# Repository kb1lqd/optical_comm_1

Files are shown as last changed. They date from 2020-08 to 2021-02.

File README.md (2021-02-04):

# optical_comm_1
Adventures in optical communications

# Lessons Learned

## Post PCB Order

Getting back into KiCAD after many years away and while focusing on my primary job and life has brought many challenges to this project. Here's the list of items I noted in the design and layout.

* I need a solid workflow for KiCAD for Symbols, Footprints, and library organization
  * I need a plan for how I want my own "Library" and process for making new boards/parts to lower the mental thought needed
  * Symbol checklist
  * Footprint Checklist
  * Sch/PCB Checklist
  * Create a template for OshPark 2/4 layer (and other vendors) to simplify future projects
* The scope of  this project ended up being quite large
* I had very little time outside of work/life to do this that intersected with my want to work on it
  * Break projects into small chunks
  * The multiplexing of jumping into this for an hour and out was very inefficient.
  * Lower the barrier to just getting a PCB in hand, refining my process, etc...
* I need more practice with KiCAD - it's different enough from Altium to be annoying and I'm not up for sitting through issues or planning after a day/week of work.

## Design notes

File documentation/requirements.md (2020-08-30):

# Requirements

### Transmitter

| Req # | Requirement | Rational |
|---|---|---|
| 1 | The transmitter shall implement amplitude modulation at baseband. | Derived |
| 2 | The transmitter shall exhibit at least 4khz of bandwidth | To support voice operations |
| 3 | The transmitter shall accept an input signal from an audio headphone output interface | Use of a computer headphone jack to provide source signals into the transmitter|
| 4 | The transmitter shall accept an input signal from a microphone interface | Use of an external microphone to provide source signals into the transmitter|
| 5 | The transmitter shall be powered from a 5V +/-250mV source | USB power |

### Receiver

| Req # | Requirement | Rational |
|---|---|---|
| 1 | The receiver shall implement amplitude modulation at baseband. | Derived |
| 2 | The receiver shall exhibit at least 4khz of bandwidth | To support voice operations |
| 3 | The receiver shall output demodulated signals from an audio headphone output level interface | Monitor headphone output|
| 4 | The receiver shall output demodulated signals from a microphone output level interface | Output provided for computer microphone input interface|
| 5 | The receiver shall be powered from a 5V +/-250mV source | USB power |

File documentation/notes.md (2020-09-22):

# Notes

## Design Notes

#### Headphones Input

Online research suggests the maximum voltage output of a headphone jack varies wildly. The output circuit itself is a low impedance amplifier that is primarily a current amplifier. It is reasonable to think that the high impedance input of the input circuits / op-amps will easily allow a maximum voltage on the input.

#### Bofeng Electret Microphone

I would like to use some spare Bofeng earpieces I have laying around. I couldn't find info sufficient to use so I cracked on open and measured while located plugged into my radio.

##### Input
* Measured ~3mVp-p while whistling at ~1.8KHz
* Electret mic is powered by 3.3V

##### Output
* ~Comfortable volume produced ~1Vp-p input earpieces
* Max volume produced ~8Vp-p

## Notes

### 9/7/2020

Today I was able to place a bulk of the transmitter circuit in LTSpice in generic format. I settled on a basic current source with pass transistor topology driving up to ~20mA at 5V. The 2 inputs are "headphones" and a "mic" input, I measured my Bofeng radio headset to get an idea where this will be in terms of signal levels and requirements.

I have been more or less rough estimating operating points, I need to go back and do the math out for fine tuning and stability. This circuit could be made to drive much higher loads if the pass transistor is made adequate, although this is a "linear" output that will dump a lot of heat into the transistor!

### 9/8/2020

Today I dove into the microphone amplifier circuitry. Assuming a nominal microphone input of 1-5mV from the electret microphone I calculated the following gains required to achieve a nominal maximum control voltage of 2.4Vp-p.

* Maximum Gain (5mVp-p): 1200 V/V   
* Minimum Gain (1mvp-p): 240 V/V

To realize this it is best split into two amplifier sub-circuits as to provide a solid fixed gain pre-amp and a variable gain final amplifier. Driving a 1200 V/V gain at 4KHz would require ~10MHz gain bandwidth product op-amp as well, easy to obtain but splitting the gain further eases this requirement. The AD8648 provides over 20MHz bandwidth and is relatively cheap.

ADS8648 Key Specs

* Vos = 2.5mV Maximum
  * All gain stages are AC coupled, 2.5mV at full scale 2.4V is negligable
* Is = 50pA Maximum worst case
  * With a 10K gain resistor this is only 0.5mV
  * With gain should match this on each input.
* Voh = 4.9V at 1mA over temp
  * Not an issue
* Vol
  * 40mV maximum over temp at 1mA.
  * Not an issue.
* GBP = 24 MHz
* Phase Margin = 74 degrees

I created a pre-amp of gain 100 V/V, the secondary gain stage is required to provide a variable 2.4V/V to 12 V/V. This is achieved by using a potentiometer in series with a minimum feedback resistor.

### 9/13/2020
Starting tonight off I need to work on the following:
* Calculate op amp gains (DONE)
  * Completed, GBP also calculated and are good.
* Calculate filter values into the LED driver at 4KHz -3dB (DONE)
* Choose MOSFET (DONE)
  * PMBF170,215	from NXP looks good. I imported the model into LTSpice. Looks good, maybe a bit lower output at lower freq.
* TO-DO: Double check op-amp stability
* Start KICAD

### 9/17/2020

TO-DO:
* Calculate:
  * Op-amp stability
  * Op-amp capacitive driver (AC coupling capacitance)
* Start KiCAD (DONE)

Status:
I was able to start KiCAD and get a new library added for the AD8648 IC. I did high level sheet creation for the transmitter and the first pass drop in of components for the microphone pre-amp stage.

### 9/20/2020

* I used LTSpice to do a quick check on op-amp stability.
* I changed the single-supply op-amp design to a voltage divider between 5V input.

### 9/21/2020

* I created an open items list on google drive
* I added audio jack with pin-outs for a kenwood style mic connector

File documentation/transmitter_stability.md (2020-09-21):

# Stability Analysis
I used open-loop analysis in LTSpice to quickly check for gain/phase margin in the op-amp circuits for the transmitter.

## Microphone Pre-amp
The microphone pre-amp is expected to have a gain of 100 V/V on the first stage and a maximum gaing of 12 V/V on stage 2. This leaves the expected bandwidth of the op-amps given the gain-bandwidth product at:

* Stage 1: 240 KHz
* Stage 2: 2.0 MHz

I setup LTSpice to perform open loop gain/phase analysis as shown below.

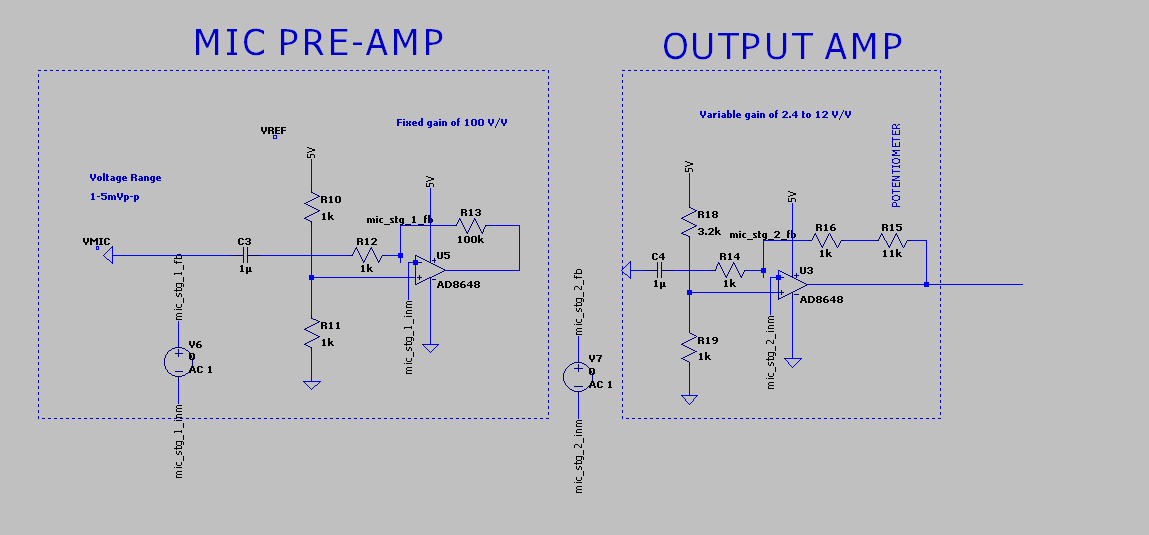
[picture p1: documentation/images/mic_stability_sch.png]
Microphone Pre-Amp Stability Analysis Schematic


The two stages showed good phase and gain margin as shown below.

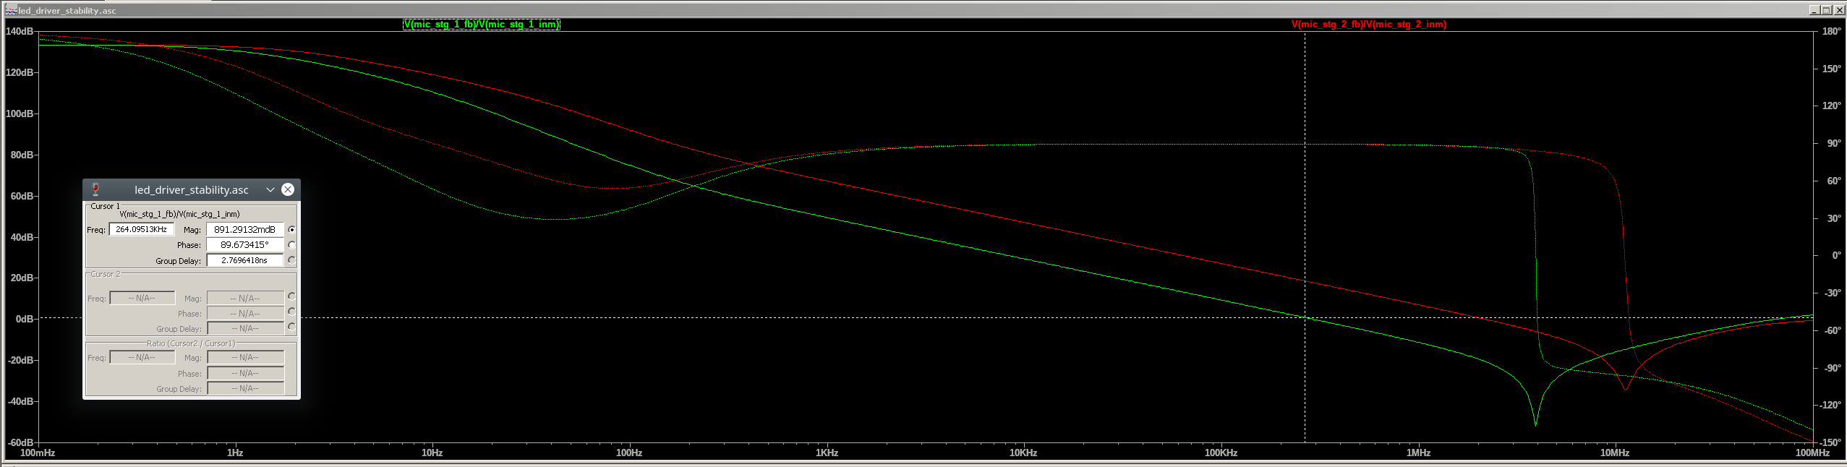
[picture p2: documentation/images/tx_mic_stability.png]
Pre-amp stage 1 gain/phase margin


Stage 1 showed ~90 degree phase margin with a unity gain bandwidth of 264 KHz, right where it was expected. Although not marked gain margin is very high, >>20dB.

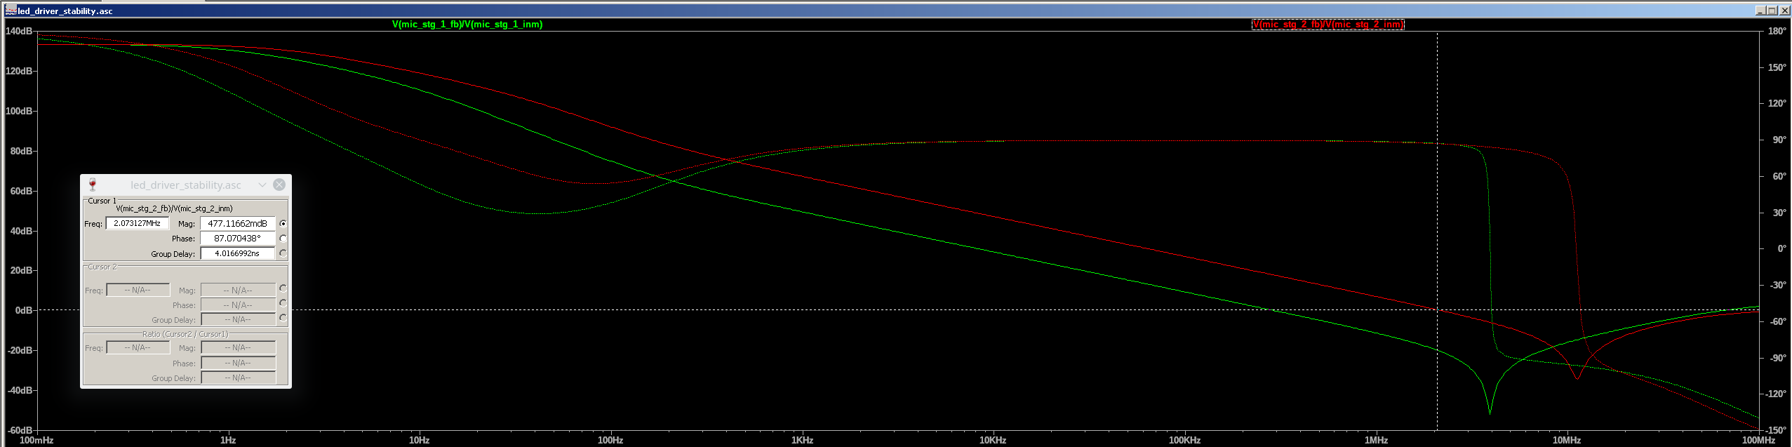
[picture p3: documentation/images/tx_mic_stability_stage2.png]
Pre-amp stage 2 gain/phase margin


Stage 2 showed ~87 degree phase margin with a unity gain bandwidth of ~2 MHz, right where it was expected. Although not marked gain margin is very high, >>20dB.

This is expected to be stable.

## Headphone Input Pre-amp
The headphone amplifier is expected to have a unity gain of 1 V/V as the input is just attenuating the strong expected headphone driver signal. This leaves the expected bandwidth of the op-amps given the gain-bandwidth product at:

* Expected Bandwidth: 24 MHz

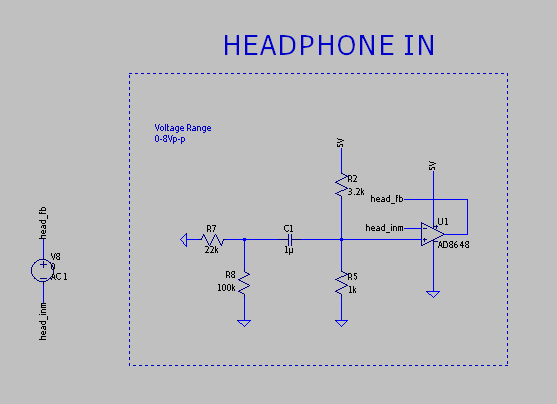
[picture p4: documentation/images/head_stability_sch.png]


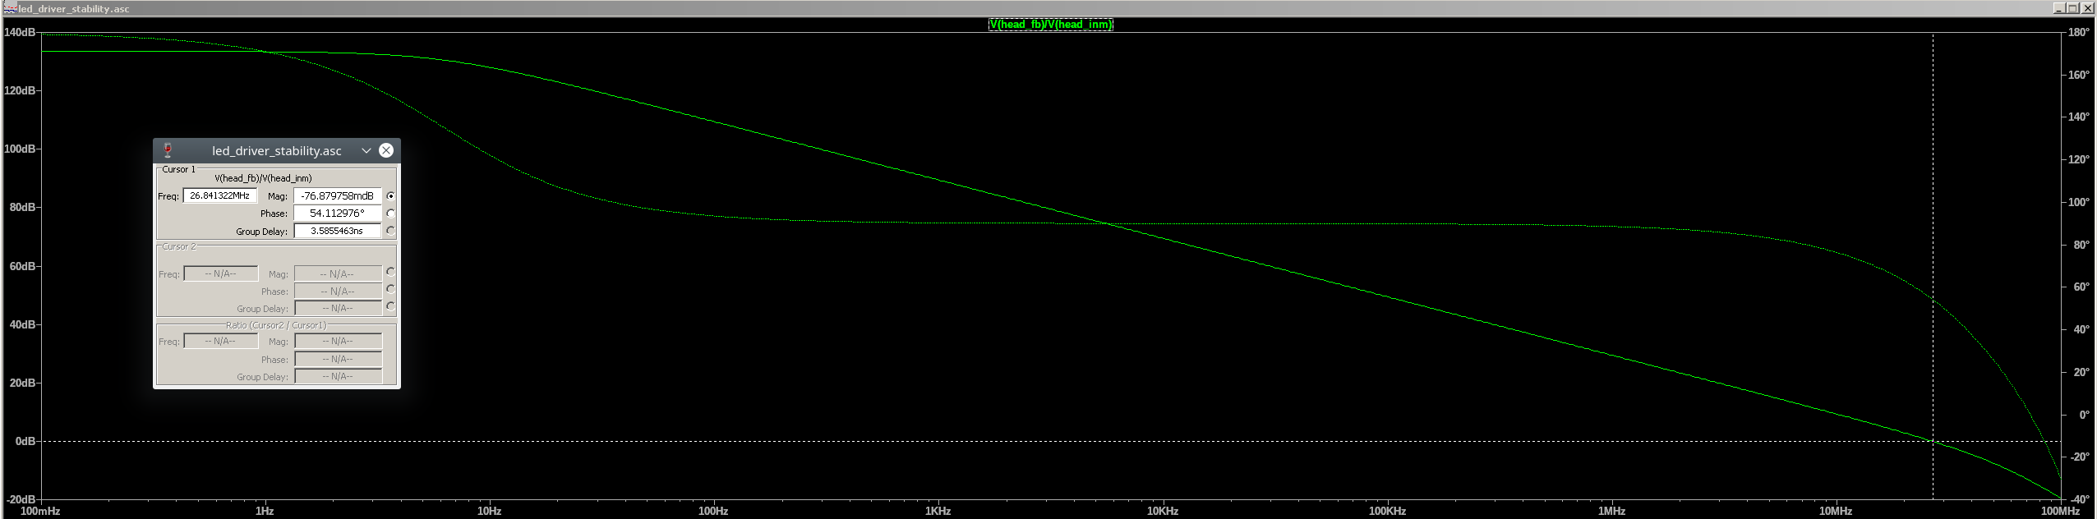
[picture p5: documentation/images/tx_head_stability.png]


The bandwidth is ~26 MHz which is approximately what was expected and a phase margin of ~56 degrees. The gain margin is not shown but is 13.7dB.

This is expected to be stable.

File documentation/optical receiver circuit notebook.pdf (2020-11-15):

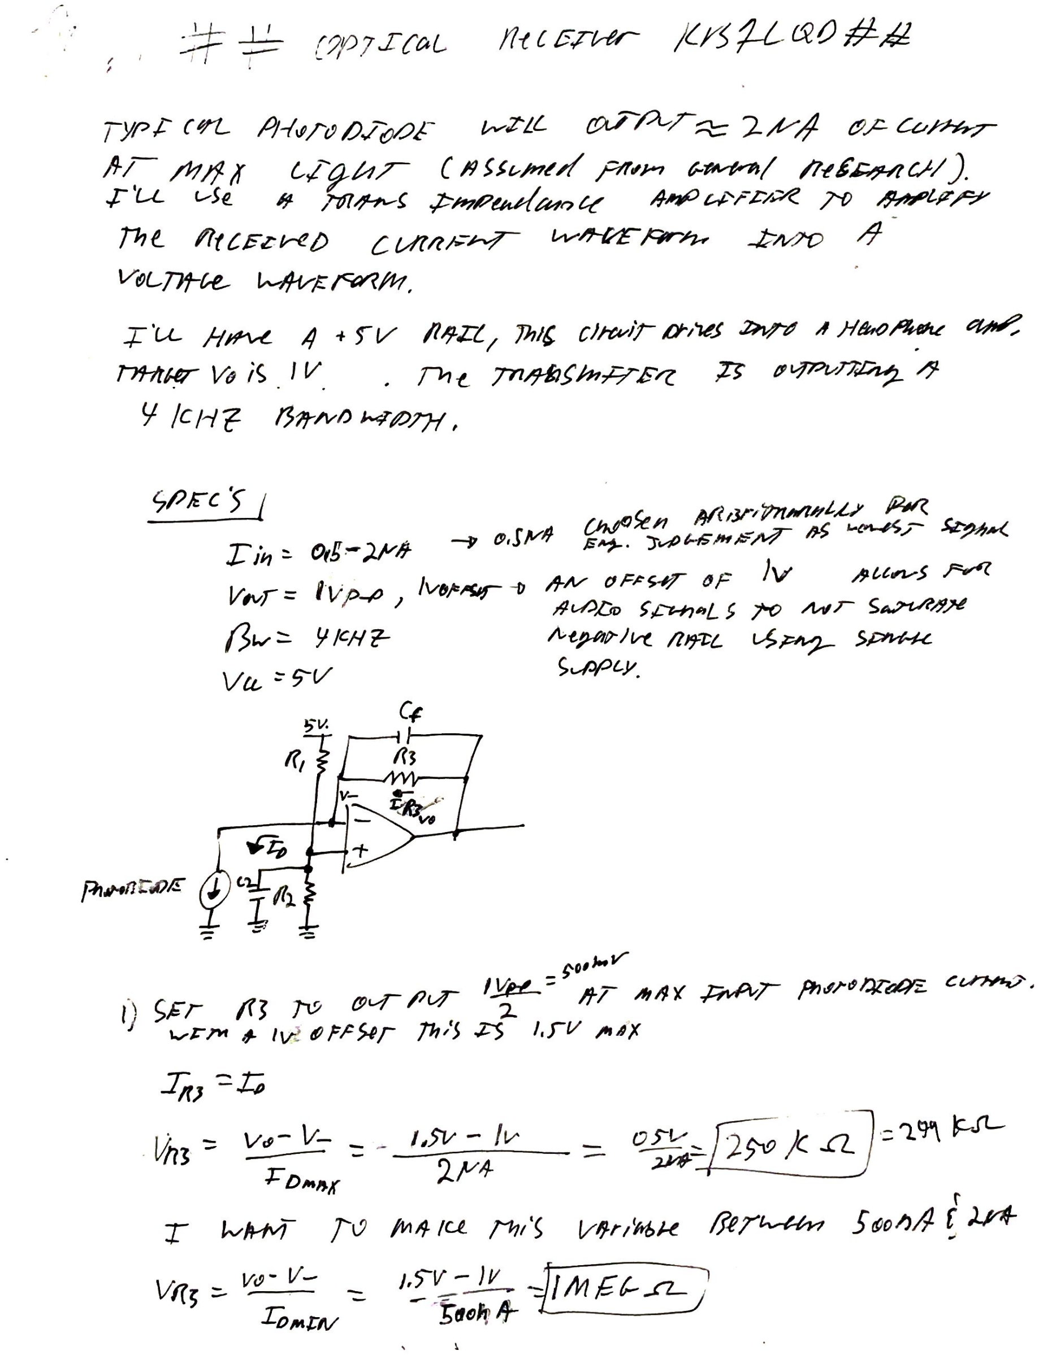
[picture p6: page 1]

(

# 1 (OPTICAL

neceiver Krstl.QD##
Typ Ece PHOTO DIODE WILL
aTnt 22NA of contat
I'LL use A Trans Impenelance And IR 70 Amplify The RECEIVED
CURRENT WAVE Form Inro
VOLTALE WAVEFORM,
I'll Have A +5V RAIL, This cirait prises Into A Meno Phone ano, Tranvet vois TV
The TRASSMETER IS OUTPUTTING A
4 IHZ BANDWIDTH,
SPEC'S
I in = 0.5-2N
→ OSMH choosen Arnimmmly PAR Eng. JUDGEMENT AS memesi Segnal lv
Allan's
Vous = lipe, vofas & AN OFFSET OF AUSEO stanals to not SavrRATE Bw=4KHZ
Negative RAIL LSing sombre Va=5v
SUPPLY
CA
50.
13
E ERSO
To
Phwonine A
16
I'
= 500mor
Ivee
out it
U) SET R3 to
AT MAX INPUT PhorontODE curr. him in offset this as usu max
In = Ie
Vorh
Uns
= 299 kr
FDMAX
200
1,5V-250kr
2NA
Want To maice this varimore Bernen 500nA & 20t -
1.5V-IV JIMEG az
IOMIN

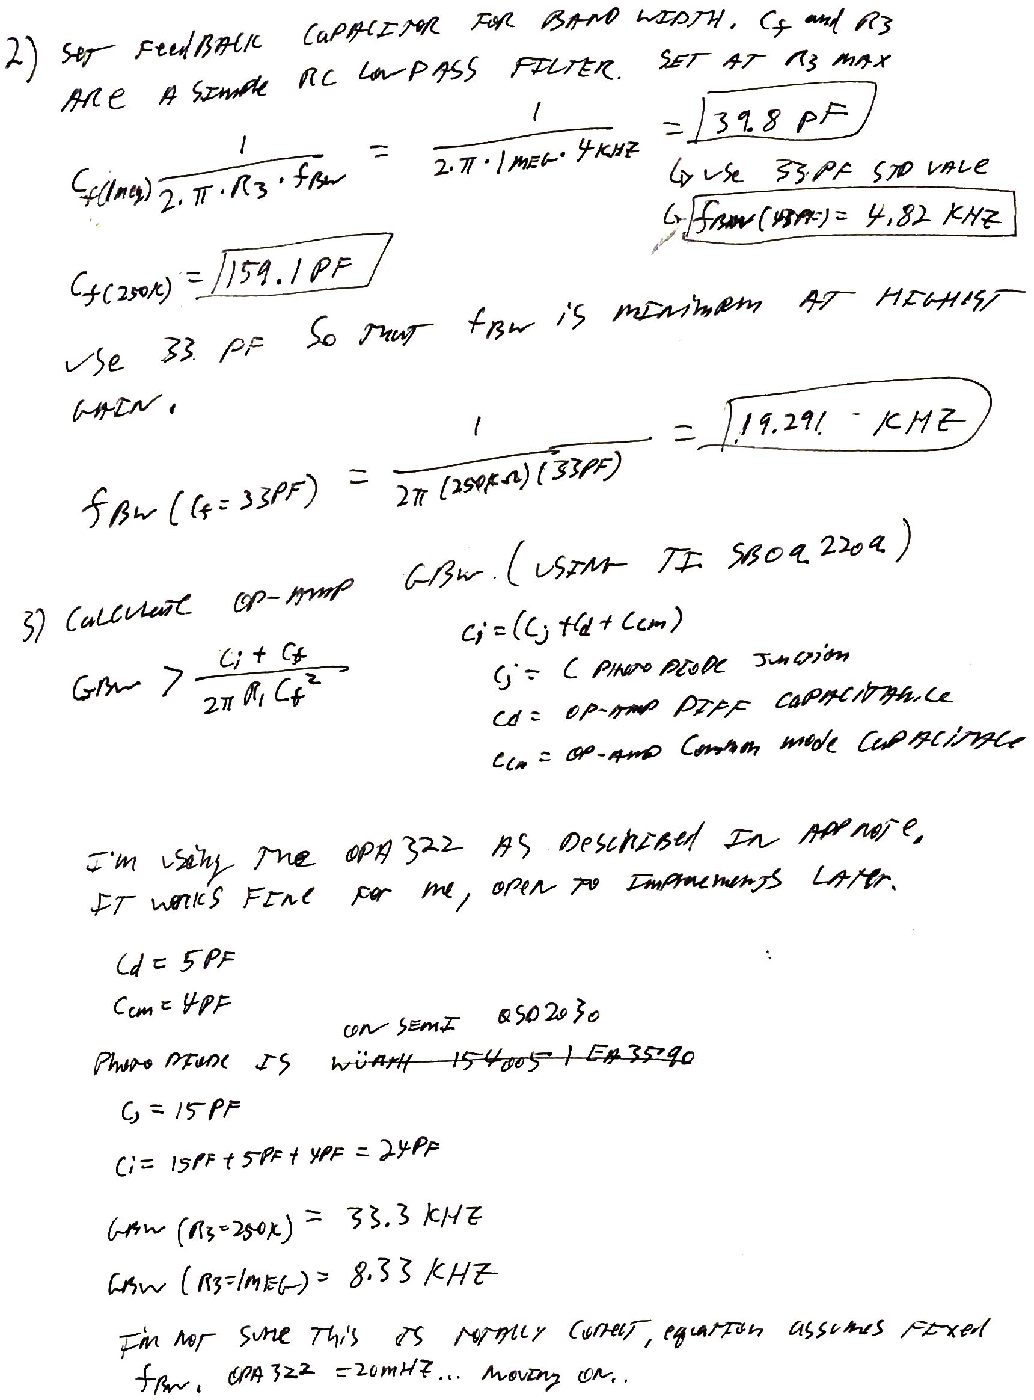
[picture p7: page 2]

SET AT 3 MAX
- for
AT HIGHEST
2) ser feel BACK CAPACITOR FOR BANO WIDTH, C, and R3 Are A simple RC Low-PASS FILTER.
= 1398 pf
Filmo) 2. I 13. f
2.7 ./ MER 4KNZ
louse 3zPF STO VALE
Glow (489x) = 4,82 KHZ
462001) = /159.1 PF
use
33. Pe
So that for is minimam
GHIN,
- 1.19.294
119.291 KHZ
fBw (( = 33PF)
GBwr. (usina TI SB0a 220a) C;' =((; Het com)
GB 7
G=C Pharo mole Jimorion
co= OP-AMP PIFF Capacitance
can P-Am Common mode Capacionce 1
=
277 (25940) (33PF)
- mm
3) Calcurant
C; + Ct
20 Ri Co²
I'm using the OPA 322 AS Deschised In App note, IT works Fine
for me,
open to Impruements LAT.
(d = 5PF
Com=YPE
on SEMI
Q50 20 30
WHATH 154005 LEA3590
Pharo mune IS
C = 15PF
(i= ISPF 15 PF + YPF = 24PF
Grow (R3=250x) = 33.3 kHz
how (R3=1MEG) = 8.33KHZ
I'm not sure This 75 mly Cuneet, equarton assumes exer for. ERA 322 =20mH?...
moving on.

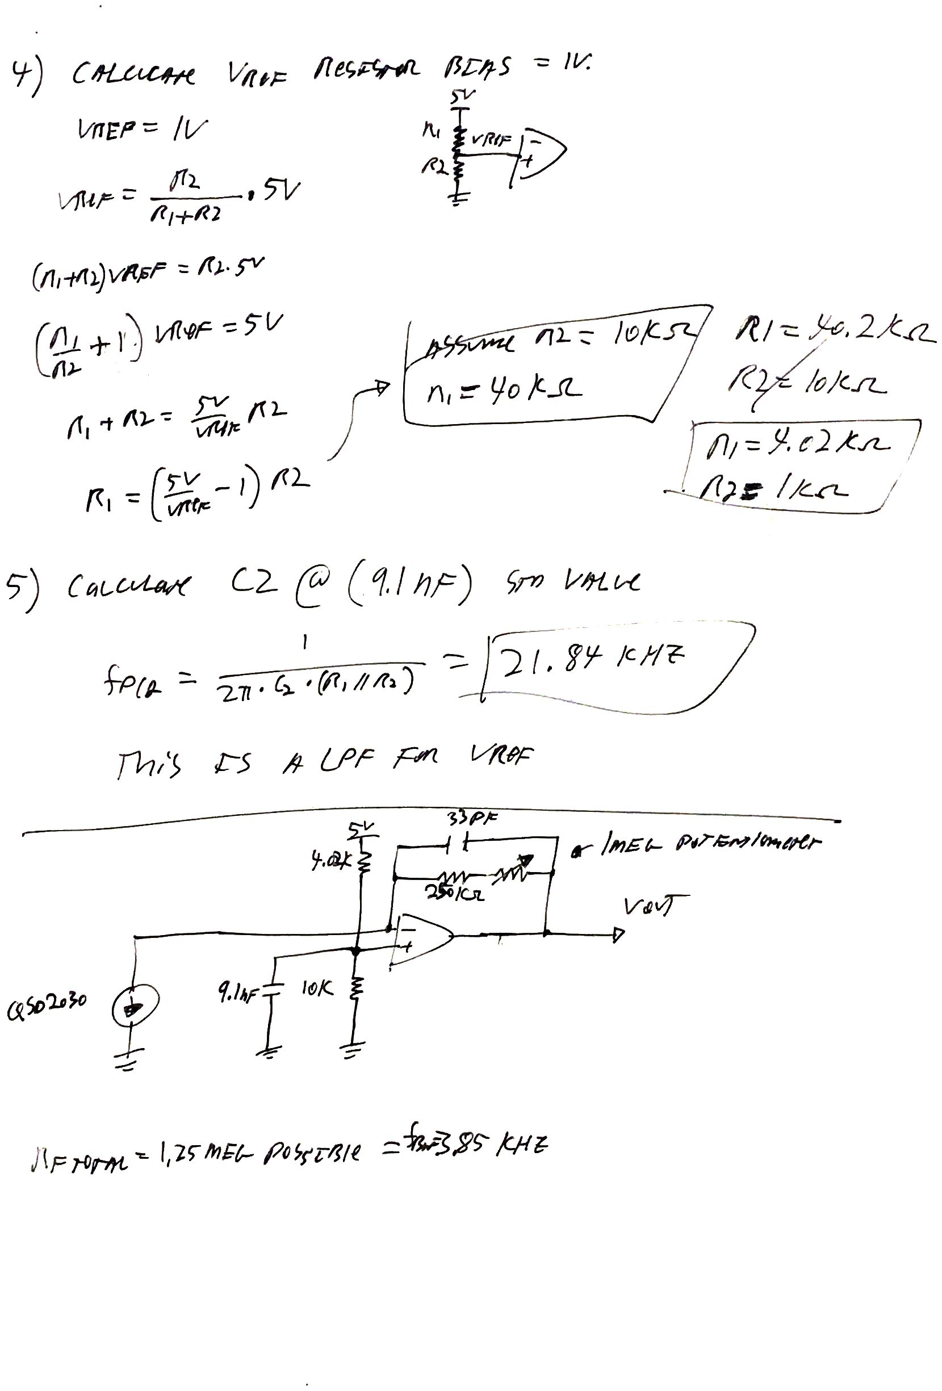
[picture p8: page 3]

= IV.
4) Calculate VroE nesesper BIMS sv
VREP = IV
no VRF
R2
..5V
era
R1+R2
(1, +92) VIREF
= 12.50
+1) nof=54
î
mir
S
1, +R2= R2
R. E
Lassume a2= loks Ri= 10.2ks n = 40kh Rhe loves
ni=1.02 kr
Elka
(su E-1) 22
5) Calculare CZ @ (.9.1 HF) SM Value face = 27627,16) = 21.84 *47
This IS ALPF FR VROF
33PF
IMEG PUTEM omever
4.at Z
moto
250142
vort
9.10F
TOK
Q502630
- from 385 kHz
From = 1,25 MEG possible =

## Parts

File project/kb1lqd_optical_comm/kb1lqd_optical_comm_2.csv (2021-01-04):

Id | Designator | Package | Quantity | Designation | Supplier and ref
1 | U2,U5 | SOIC-8_3.9x4.9mm_P1.27mm | 2 | AD8646
2 | H4,H3,H2,H1 | MountingHole_4.3mm_M4_DIN965_Pad | 4 | MountingHole_Pad
3 | J6,J3,J1 | CUI_SJ1-3523N | 3 | SJ1-3523N
4 | SW1,SW3,SW2 | SW_EG1213 | 3 | EG1213
5 | C20,C12,C6 | C_0805_2012Metric | 3 | DNP
6 | U4 | TPA6111A2D | 1 | TPA6111A2D
7 | U3 | SOIC-8_3.9x4.9mm_P1.27mm | 1 | ADA4610-1
8 | RV2,RV1 | Molex_KK-254_AE-6410-04A_1x04_P2.54mm_Vertical | 2 | 50k
9 | R34 | R_0805_2012Metric | 1 | 100k
10 | R33,R32,R17,R4,R3,R1 | R_0603_1608Metric | 6 | 0
11 | R31,R30,R29,R28,R26,R25,R13,R8,R7,R6,R5,R2 | R_0603_1608Metric | 12 | 10k
12 | R27 | R_0603_1608Metric | 1 | 500k
13 | R24,R23,R22,R20,R19,R15,R10 | R_0603_1608Metric | 7 | 1k
14 | R21,R18 | R_0603_1608Metric | 2 | 3.24k
15 | R16,R14,R11,R9 | R_0603_1608Metric | 4 | 3.2k
16 | R12 | R_0603_1608Metric | 1 | 140
17 | Q1 | SOT-23 | 1 | PMBF170
18 | J5 | Molex_KK-254_AE-6410-02A_1x02_P2.54mm_Vertical | 1 | Conn_01x02_Male
19 | J4 | Molex_KK-254_AE-6410-04A_1x04_P2.54mm_Vertical | 1 | Conn_01x04_Male
20 | J2 | CUI_SJ-2509N | 1 | SJ-2509N
21 | D2 | TO-18-2 | 1 | ODD-1W
22 | D1 | LED_D5.0mm | 1 | VLCS5830
23 | C23,C17,C9 | C_0805_2012Metric | 3 | 100nF
24 | C22,C21 | C_0603_1608Metric | 2 | DNP
25 | C19,C18,C15,C14,C13,C11 | C_1206_3216Metric | 6 | 1uF
26 | C16 | CP_Elec_5x5.3 | 1 | 10uF
27 | C10 | C_0603_1608Metric | 1 | 33pF
28 | C8 | C_0805_2012Metric | 1 | 6.8nF
29 | C7,C5,C4,C3,C2 | C_1206_3216Metric | 5 | 1u
30 | C1 | C_0805_2012Metric | 1 | 3.9n

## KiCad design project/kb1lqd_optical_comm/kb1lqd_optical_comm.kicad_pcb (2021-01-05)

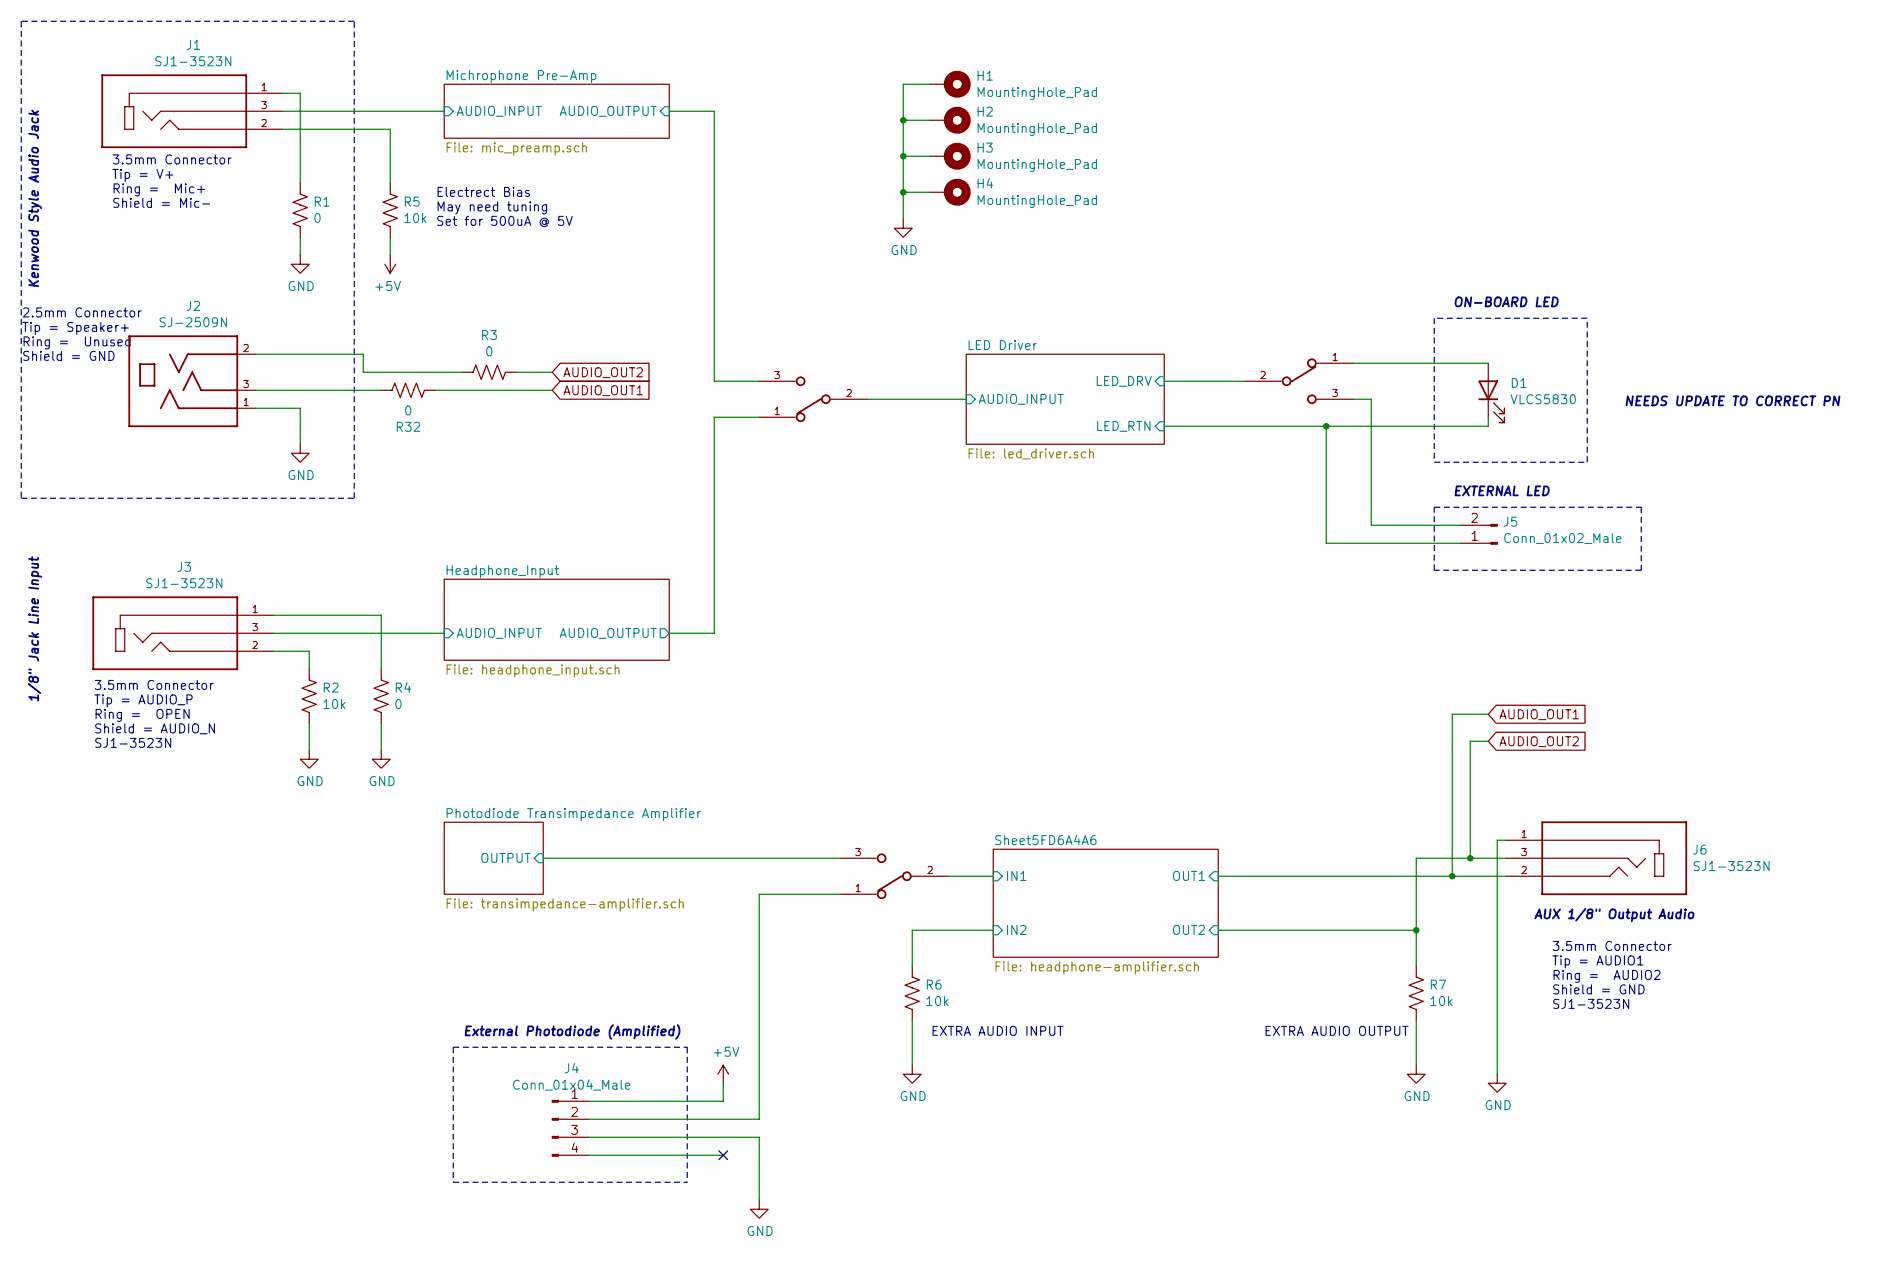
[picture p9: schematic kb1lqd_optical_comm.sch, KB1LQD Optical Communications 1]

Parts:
D1: VLCS5830; LED_D5.0mm
H1, H2, H3, H4: MountingHole_Pad; MountingHole_4.3mm_M4_DIN965_Pad
J1, J3, J6: SJ1-3523N; CUI_SJ1-3523N; PARTREV 1.02
J2: SJ-2509N; CUI_SJ-2509N; PART_REV B
J4: Conn_01x04_Male; Molex_KK-254_AE-6410-04A_1x04_P2.54mm_Vertical
J5: Conn_01x02_Male; Molex_KK-254_AE-6410-02A_1x02_P2.54mm_Vertical
R1, R3, R4, R32: 0; R_0603_1608Metric
R2, R5, R6, R7: 10k; R_0603_1608Metric
SW1, SW2, SW3: EG1213; SW_EG1213

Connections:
+5V: J4.1, R5.2, SW3.2; also elsewhere on the board
/Headphone_Input/AUDIO_INPUT: J3.3; also elsewhere on the board
/Headphone_Input/AUDIO_OUTPUT: SW1.1; also elsewhere on the board
/LED Driver/AUDIO_INPUT: SW1.2; also elsewhere on the board
/LED Driver/LED_RTN: D1.1 (K), J5.1; also elsewhere on the board
/Michrophone Pre-Amp/AUDIO_INPUT: J1.3; also elsewhere on the board
/Michrophone Pre-Amp/AUDIO_OUTPUT: SW1.3; also elsewhere on the board
/Photodiode Transimpedance Amplifier/OUTPUT: SW2.3; also elsewhere on the board
/Sheet5FD6A4A6/IN1: SW2.2; also elsewhere on the board
/Sheet5FD6A4A6/IN2: R6.1; also elsewhere on the board
AUDIO_OUT1: J6.2, R32.2; also elsewhere on the board
AUDIO_OUT2: J6.3, R3.1, R7.1; also elsewhere on the board
GND: H1.1, H2.1, H3.1, H4.1, J2.1, J4.3, J6.1, R1.2, R2.2, R4.2, R6.2, R7.2; also elsewhere on the board
unnamed: D1.2 (A), SW3.1
unnamed: J1.1, R1.1
unnamed: J1.2, R5.1
unnamed: J2.2, R3.2
unnamed: J2.3, R32.1
unnamed: J3.1, R4.1
unnamed: J3.2, R2.1
unnamed: J4.2, SW2.1
unnamed: J5.2, SW3.3

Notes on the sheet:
3.5mm Connector Tip = V+ Ring = Mic+ Shield = Mic-
2.5mm Connector Tip = Speaker+ Ring = Unused Shield = GND
Electrect Bias May need tuning Set for 500uA @ 5V
ON-BOARD LED
EXTERNAL LED
NEEDS UPDATE TO CORRECT PN
External Photodiode (Amplified)
3.5mm Connector Tip = AUDIO_P Ring = OPEN Shield = AUDIO_N SJ1-3523N
EXTRA AUDIO INPUT
EXTRA AUDIO OUTPUT
3.5mm Connector Tip = AUDIO1 Ring = AUDIO2 Shield = GND SJ1-3523N
AUX 1/8" Output Audio
Kenwood Style Audio Jack
1/8" Jack Line Input

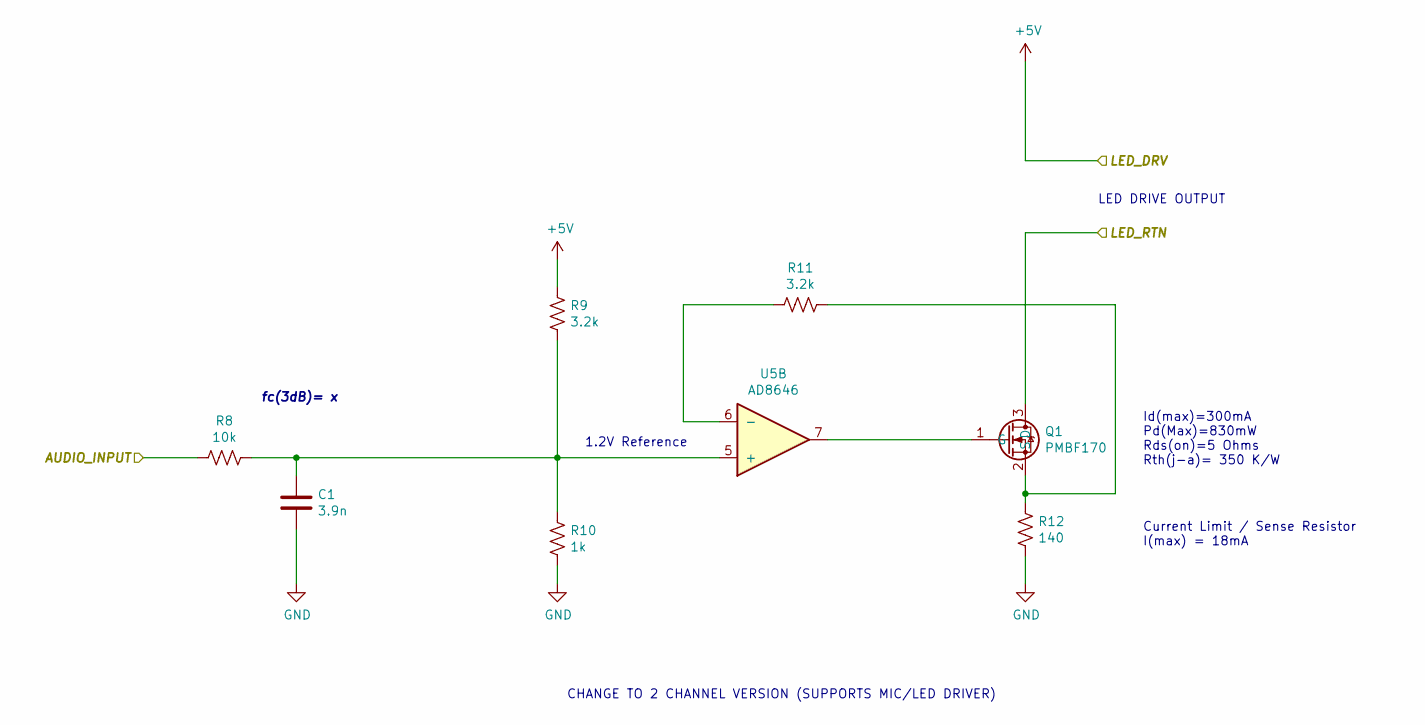
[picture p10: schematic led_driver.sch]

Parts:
C1: 3.9n; C_0805_2012Metric
Q1: PMBF170; SOT-23
R8: 10k; R_0603_1608Metric
R9, R11: 3.2k; R_0603_1608Metric
R10: 1k; R_0603_1608Metric
R12: 140; R_0603_1608Metric
U5: AD8646; SOIC-8_3.9x4.9mm_P1.27mm

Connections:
+5V: R9.1; also elsewhere on the board
/LED Driver/AUDIO_INPUT: R8.2; also elsewhere on the board
/LED Driver/LED_RTN: Q1.3 (D); also elsewhere on the board
GND: C1.2, R10.2, R12.2; also elsewhere on the board
unnamed: C1.1, R8.1, R9.2, R10.1, U5.5 (+)
unnamed: Q1.1 (G), U5.7
unnamed: Q1.2 (S), R11.1, R12.1
unnamed: R11.2, U5.6 (-)

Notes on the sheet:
LED DRIVE OUTPUT
1.2V Reference
fc(3dB)= x
Id(max)=300mA Pd(Max)=830mW Rds(on)=5 Ohms Rth(j-a)= 350 K/W
Current Limit / Sense Resistor I(max) = 18mA
CHANGE TO 2 CHANNEL VERSION (SUPPORTS MIC/LED DRIVER)

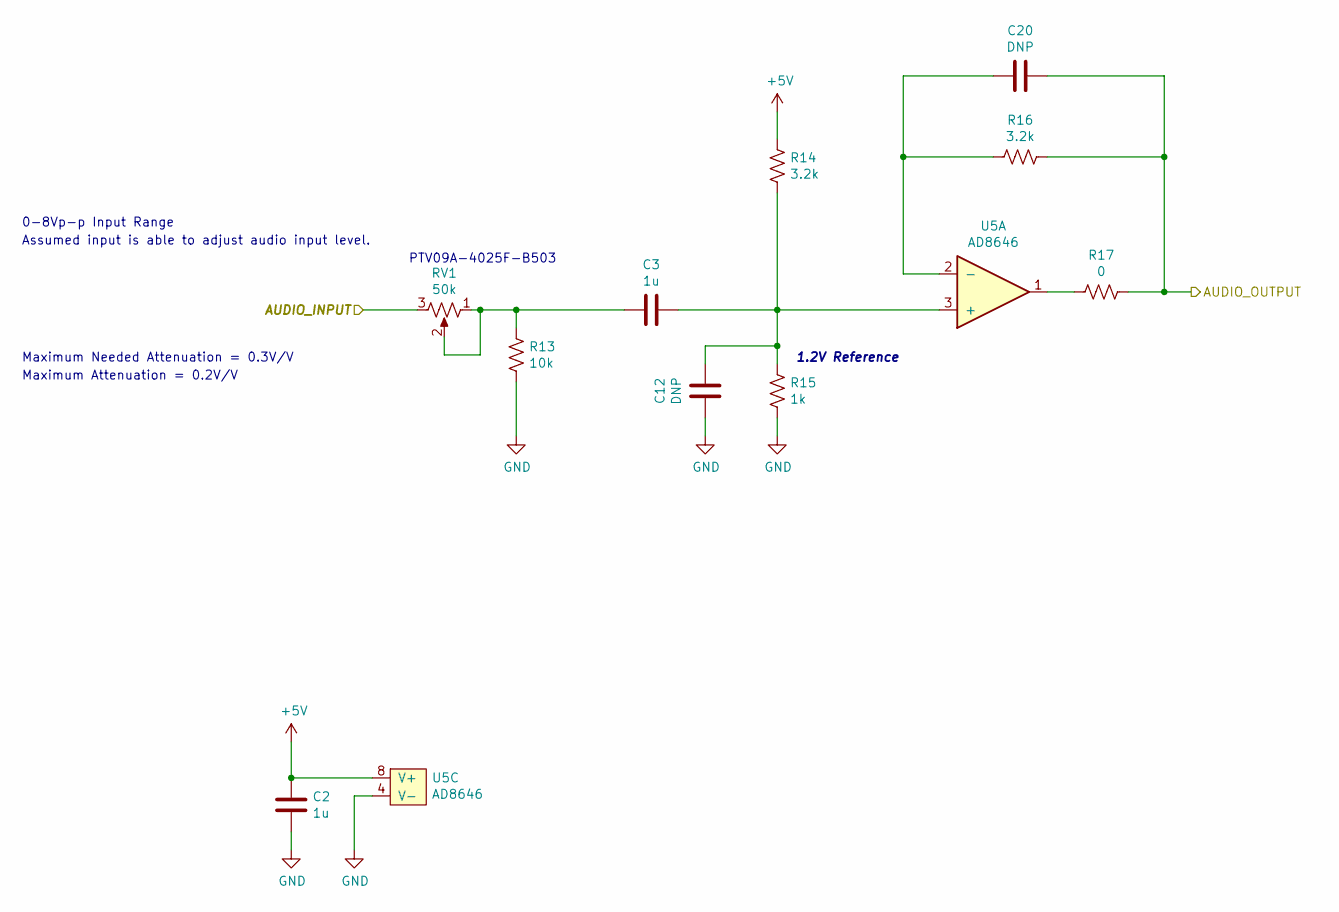
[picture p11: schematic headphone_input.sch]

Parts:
C2, C3: 1u; C_1206_3216Metric
C12, C20: DNP; C_0805_2012Metric
R13: 10k; R_0603_1608Metric
R14, R16: 3.2k; R_0603_1608Metric
R15: 1k; R_0603_1608Metric
R17: 0; R_0603_1608Metric
RV1: 50k; Molex_KK-254_AE-6410-04A_1x04_P2.54mm_Vertical
U5: AD8646; SOIC-8_3.9x4.9mm_P1.27mm

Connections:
+5V: C2.2, R14.1, U5.8 (V+); also elsewhere on the board
/Headphone_Input/AUDIO_INPUT: RV1.3; also elsewhere on the board
/Headphone_Input/AUDIO_OUTPUT: C20.1, R16.1, R17.1; also elsewhere on the board
GND: C2.1, C12.2, R13.2, R15.2, U5.4 (V-); also elsewhere on the board
unnamed: C3.2, R13.1, RV1.1, RV1.2
unnamed: C3.1, C12.1, R14.2, R15.1, U5.3 (+)
unnamed: C20.2, R16.2, U5.2 (-)
unnamed: R17.2, U5.1

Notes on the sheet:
1.2V Reference
0-8Vp-p Input Range
Assumed input is able to adjust audio input level.
Maximum Needed Attenuation = 0.3V/V
Maximum Attenuation = 0.2V/V
PTV09A-4025F-B503

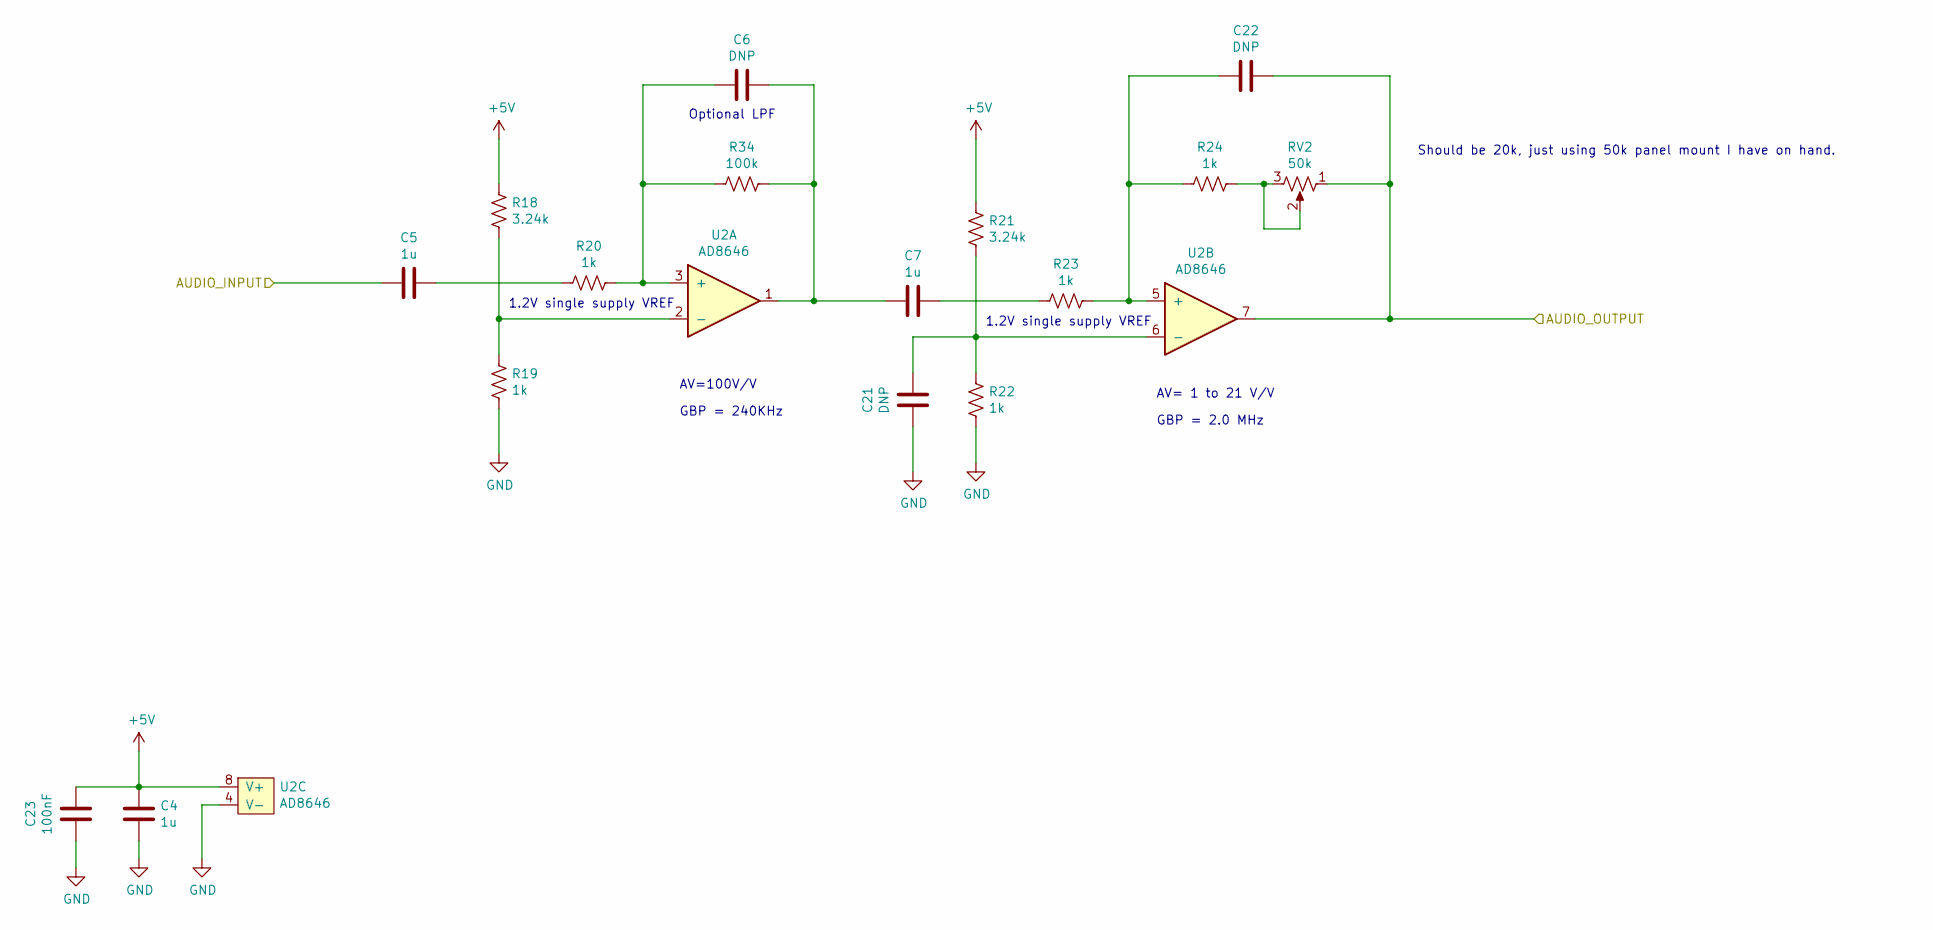
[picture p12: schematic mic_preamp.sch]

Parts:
C4, C5, C7: 1u; C_1206_3216Metric
C6: DNP; C_0805_2012Metric
C21, C22: DNP; C_0603_1608Metric
C23: 100nF; C_0805_2012Metric
R18, R21: 3.24k; R_0603_1608Metric
R19, R20, R22, R23, R24: 1k; R_0603_1608Metric
R34: 100k; R_0805_2012Metric
RV2: 50k; Molex_KK-254_AE-6410-04A_1x04_P2.54mm_Vertical
U2: AD8646; SOIC-8_3.9x4.9mm_P1.27mm

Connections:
+5V: C4.2, C23.1, R18.2, R21.2, U2.8 (V+); also elsewhere on the board
/Michrophone Pre-Amp/AUDIO_INPUT: C5.2; also elsewhere on the board
/Michrophone Pre-Amp/AUDIO_OUTPUT: C22.1, RV2.1, U2.7; also elsewhere on the board
GND: C4.1, C21.2, C23.2, R19.1, R22.1, U2.4 (V-); also elsewhere on the board
unnamed: C5.1, R20.2
unnamed: C6.1, C7.2, R34.1, U2.1
unnamed: C6.2, R20.1, R34.2, U2.3 (+)
unnamed: C7.1, R23.2
unnamed: C21.1, R21.1, R22.2, U2.6 (-)
unnamed: C22.2, R23.1, R24.2, U2.5 (+)
unnamed: R18.1, R19.2, U2.2 (-)
unnamed: R24.1, RV2.2, RV2.3

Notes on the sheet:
AV=100V/V
AV= 1 to 21 V/V
1.2V single supply VREF
GBP = 240KHz
GBP = 2.0 MHz
Optional LPF
Should be 20k, just using 50k panel mount I have on hand.

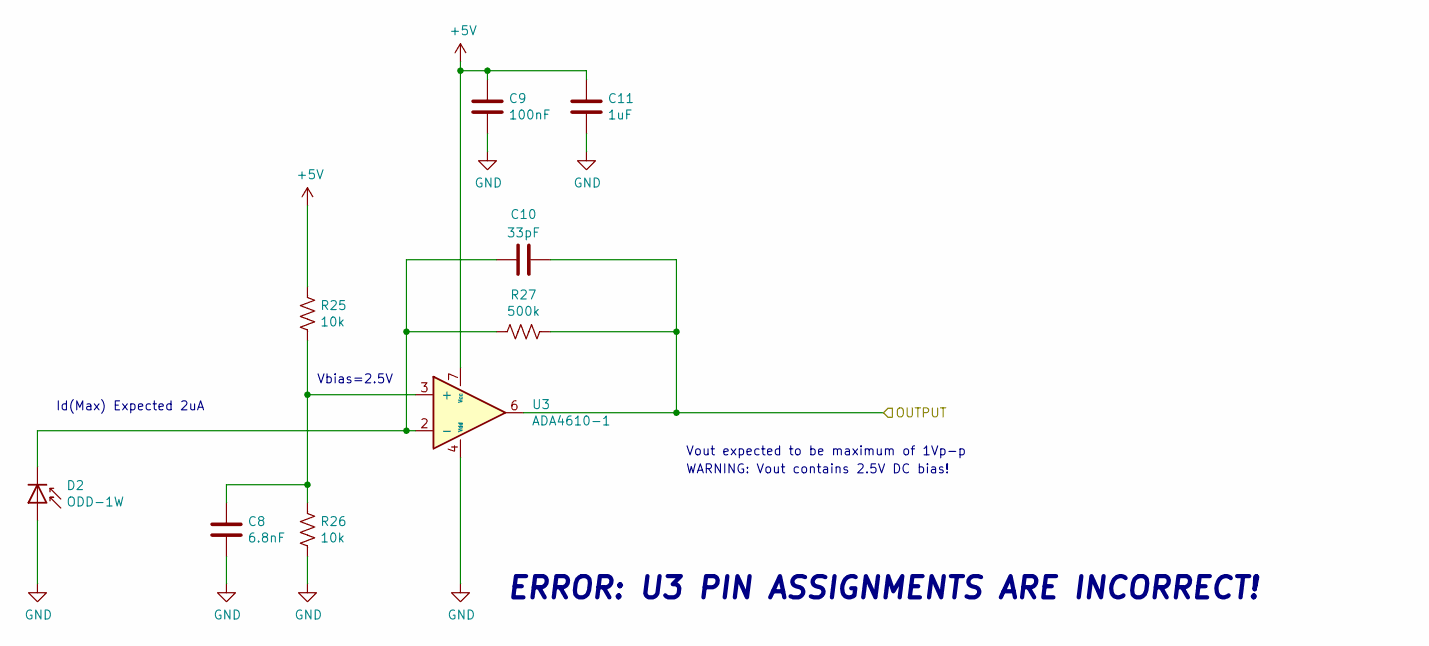
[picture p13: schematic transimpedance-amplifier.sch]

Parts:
C8: 6.8nF; C_0805_2012Metric
C9: 100nF; C_0805_2012Metric
C10: 33pF; C_0603_1608Metric
C11: 1uF; C_1206_3216Metric
D2: ODD-1W; TO-18-2
R25, R26: 10k; R_0603_1608Metric
R27: 500k; R_0603_1608Metric
U3: ADA4610-1; SOIC-8_3.9x4.9mm_P1.27mm

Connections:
+5V: C9.1, C11.1, R25.1, U3.7 (Vcc); also elsewhere on the board
/Photodiode Transimpedance Amplifier/OUTPUT: C10.1, R27.1, U3.6; also elsewhere on the board
GND: C8.2, C9.2, C11.2, D2.2 (A), R26.2, U3.4 (Vdd); also elsewhere on the board
unnamed: C8.1, R25.2, R26.1, U3.3 (+)
unnamed: C10.2, D2.1 (K), R27.2, U3.2 (-)

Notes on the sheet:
Id(Max) Expected 2uA
Vout expected to be maximum of 1Vp-p
Vbias=2.5V
WARNING: Vout contains 2.5V DC bias!
ERROR: U3 PIN ASSIGNMENTS ARE INCORRECT!

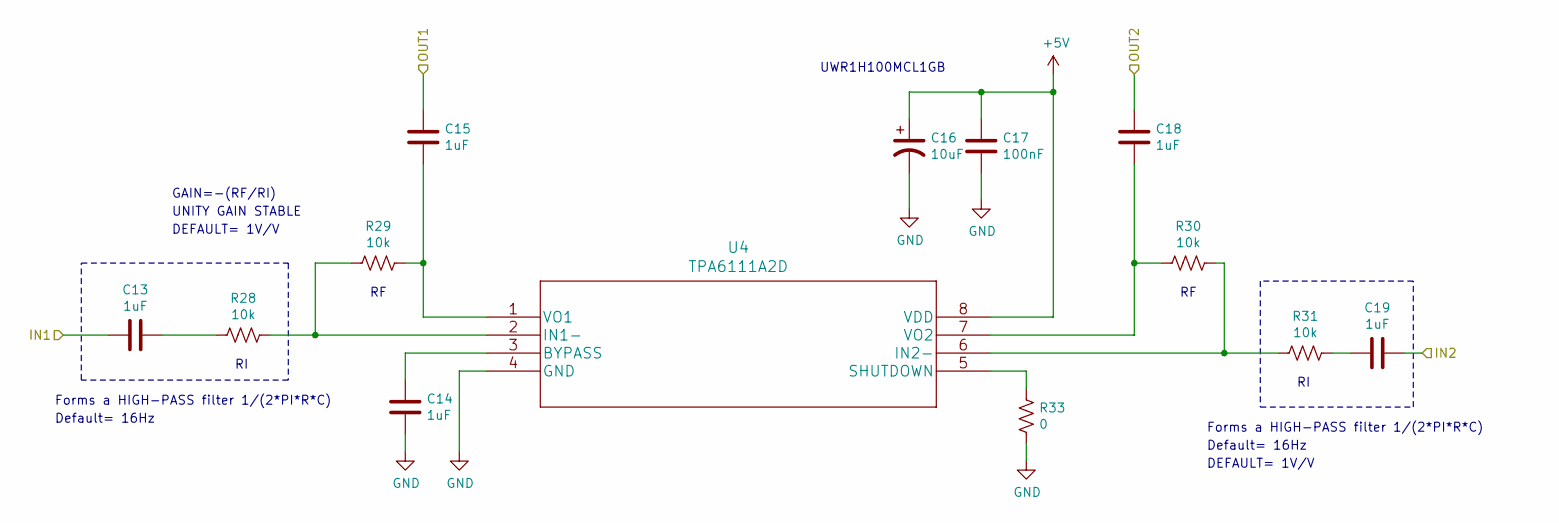
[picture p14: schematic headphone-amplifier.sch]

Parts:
C13, C14, C15, C18, C19: 1uF; C_1206_3216Metric
C16: 10uF; CP_Elec_5x5.3
C17: 100nF; C_0805_2012Metric
R28, R29, R30, R31: 10k; R_0603_1608Metric
R33: 0; R_0603_1608Metric
U4: TPA6111A2D

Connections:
+5V: C16.1, C17.2, U4.8 (VDD); also elsewhere on the board
/Sheet5FD6A4A6/IN1: C13.1; also elsewhere on the board
/Sheet5FD6A4A6/IN2: C19.2; also elsewhere on the board
AUDIO_OUT1: C15.2; also elsewhere on the board
AUDIO_OUT2: C18.2; also elsewhere on the board
GND: C14.1, C16.2, C17.1, R33.1, U4.4 (GND); also elsewhere on the board
unnamed: C13.2, R28.2
unnamed: C14.2, U4.3 (BYPASS)
unnamed: C15.1, R29.1, U4.1 (VO1)
unnamed: C18.1, R30.2, U4.7 (VO2)
unnamed: C19.1, R31.1
unnamed: R28.1, R29.2, U4.2 (IN1-)
unnamed: R30.1, R31.2, U4.6 (IN2-)
unnamed: R33.2, U4.5 (SHUTDOWN)

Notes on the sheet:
GAIN=-(RF/RI)
UNITY GAIN STABLE
Forms a HIGH-PASS filter 1/(2*PI*R*C)
Default= 16Hz
DEFAULT= 1V/V
UWR1H100MCL1GB

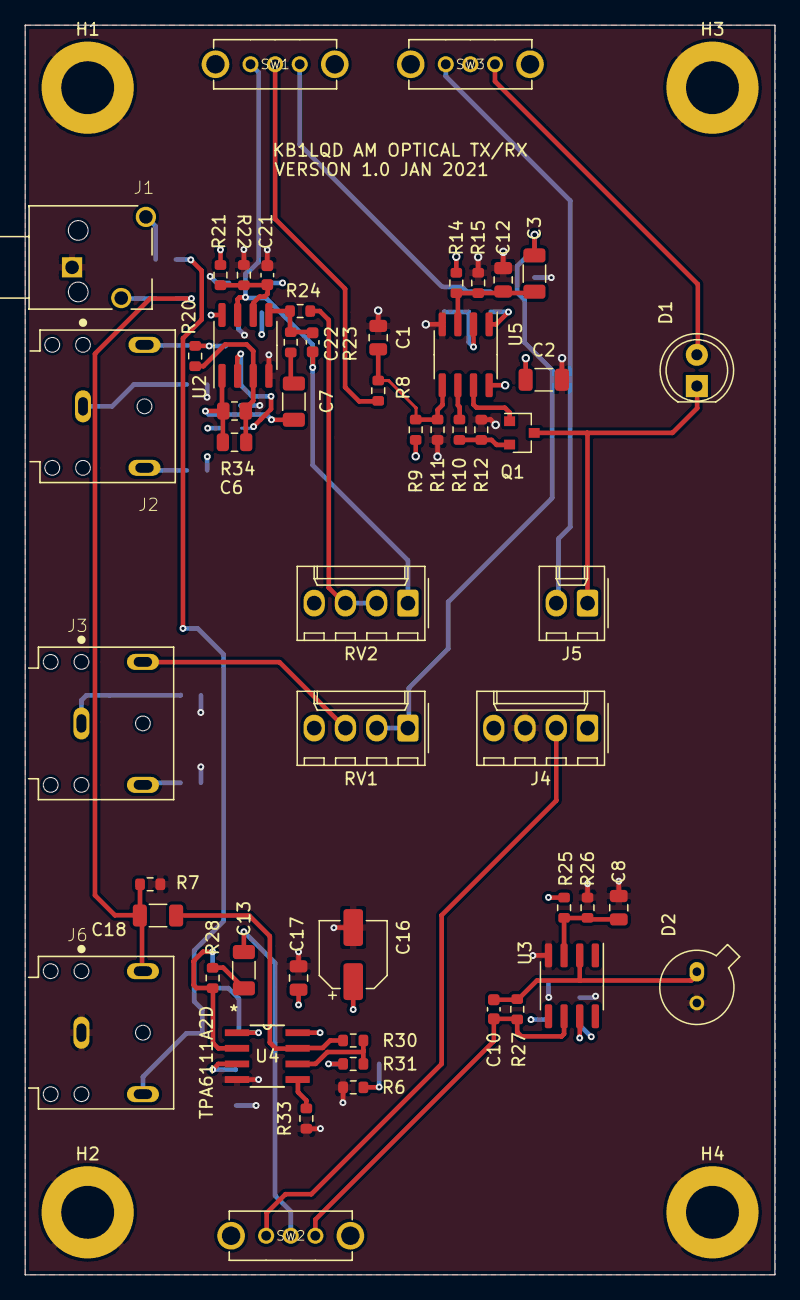
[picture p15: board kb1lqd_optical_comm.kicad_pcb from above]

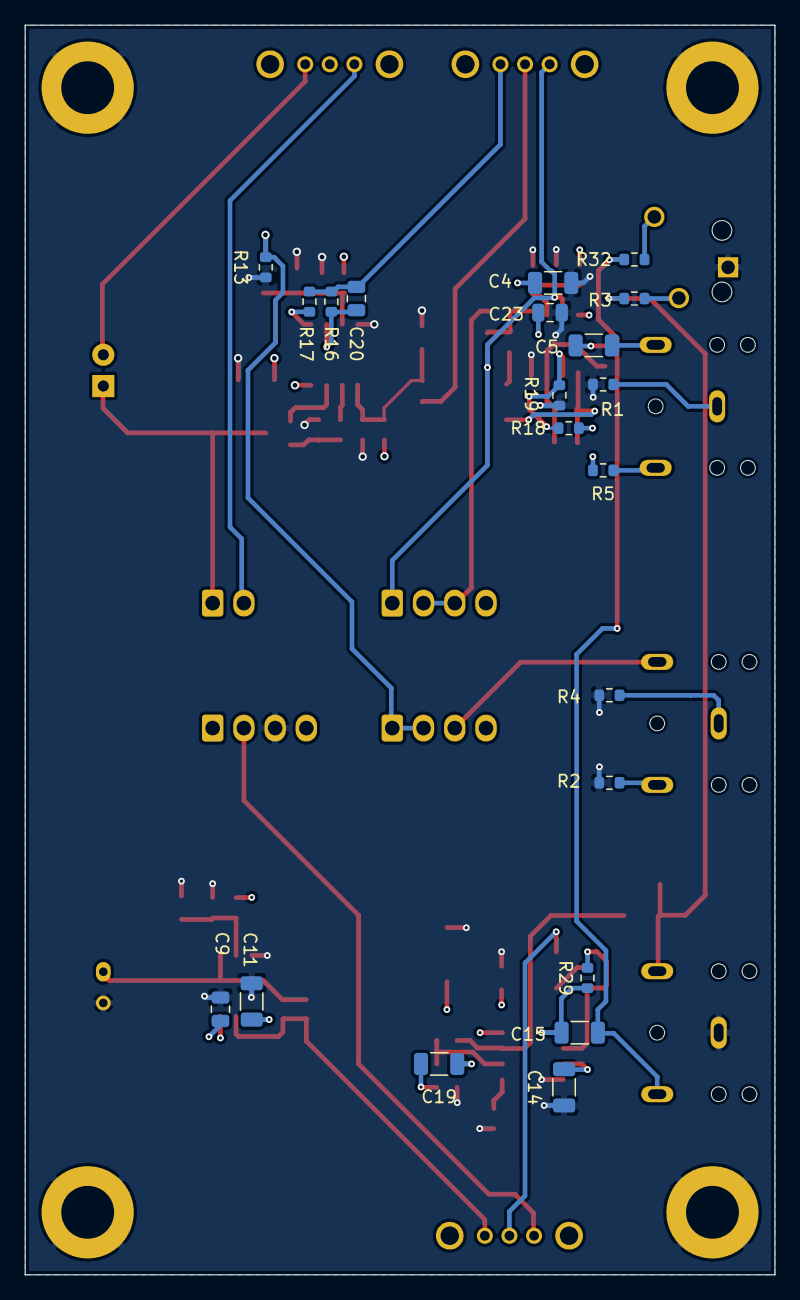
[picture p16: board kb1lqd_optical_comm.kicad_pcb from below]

Board: 4 copper layers, 61.0 x 101.6 mm, 79 parts (21 on the bottom side), 48 nets.

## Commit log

2020-09-07 Working current source
2020-09-07 Initial driver ipython.
2020-09-09 Updated mic pre-amp and output stage.
2020-09-14 Updating with RC filter, correct MOSFET.
2020-09-18 Adding KiCAD initial project.
    [headphone_input.sch, kb1lqd_optical_comm.kicad_pcb, kb1lqd_optical_comm.sch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]
2020-09-21 Updated with better values and text.
    [headphone_input.sch, kb1lqd_optical_comm.sch, led_driver.sch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]
2020-09-21 Adding updates.
    [headphone_input.sch, kb1lqd_optical_comm.sch, led_driver.sch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]
2020-09-22 Adding updates for 9/21/2020
    [headphone_input.sch, kb1lqd_optical_comm.sch, mic_preamp.sch]
2020-09-22 Updated jack todo text.
    [kb1lqd_optical_comm.sch]
2020-09-23 Adding audio jack symbols.
    [kb1lqd_optical_comm.sch]
2020-09-23 Adding KK 100 series connector.
    [kb1lqd_optical_comm.sch]
2020-09-23 Adding SPDT switch.
    [kb1lqd_optical_comm.sch]
2020-12-13 adding recevier transimpedance amp. Adding simulations.
    [headphone_input.sch, kb1lqd_optical_comm.sch, led_driver.sch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]
2020-12-13 Schematic essentially done.
    [headphone-amplifier.sch, headphone_input.sch, kb1lqd_optical_comm.sch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]
2020-12-13 Fixing ERC errors.
    [headphone-amplifier.sch, headphone_input.sch, kb1lqd_optical_comm.sch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]
2020-12-27 Updated with all footprints
    [headphone-amplifier.sch, headphone_input.sch, kb1lqd_optical_comm.sch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]
2020-12-27 Updated with osh park board template rules.
    [kb1lqd_oshpark-4layer-template.kicad_pcb]
2020-12-27 Initial placement mostly done. Outlined PCB.
    [headphone_input.sch, kb1lqd_optical_comm.kicad_pcb, led_driver.sch]
2020-12-27 Initial placement condensed.
    [headphone_input.sch, kb1lqd_optical_comm.kicad_pcb, kb1lqd_optical_comm.sch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]
2020-12-27 More placement. Ready for board outline update.
    [kb1lqd_optical_comm.kicad_pcb, kb1lqd_optical_comm.sch]
2020-12-28 Placement done.
    [kb1lqd_optical_comm.kicad_pcb]
2020-12-28 Moved silkscreen references.
    [kb1lqd_optical_comm.kicad_pcb]
2020-12-28 Most of initial routing completed.
    [kb1lqd_optical_comm.kicad_pcb]
2021-01-01 Finished initial board. Downloaded audio jack footprint is causing errors on edge cut layer.
    [kb1lqd_optical_comm.kicad_pcb]
2021-01-01 No DRC errors.
    [kb1lqd_optical_comm.kicad_pcb]
2021-01-01 Updated mounting holes. Created BOM.
    [kb1lqd_optical_comm.csv, kb1lqd_optical_comm.kicad_pcb, kb1lqd_optical_comm.sch]
2021-01-04 Updated u2 to soic 8
    [kb1lqd_optical_comm.kicad_pcb, mic_preamp.sch]
2021-01-04 Updated to new soic footprint.
    [kb1lqd_optical_comm.kicad_pcb, kb1lqd_optical_comm_2.csv]
2021-01-05 Fixed a few errors in silkscreen, found an open item error in U3 generated footprint.
    [kb1lqd_optical_comm-B_Cu.gbl, kb1lqd_optical_comm-B_Mask.gbs, kb1lqd_optical_comm-B_SilkS.gbo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]
2021-02-04 Ordered this, checked U3 and other IC's and didn't find any issues...
    [kb1lqd_optical_comm-B_Cu.gbl, kb1lqd_optical_comm-B_Mask.gbs, kb1lqd_optical_comm-B_SilkS.gbo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]
2021-02-04 Adding lessons learned post PCB order.

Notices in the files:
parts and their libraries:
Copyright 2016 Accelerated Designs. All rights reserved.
